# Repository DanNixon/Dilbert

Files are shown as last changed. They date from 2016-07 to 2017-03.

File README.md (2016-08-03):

# Dilbert



An interactive badge based on the ESP8266.

For getting started and general information see [GUIDE.md](GUIDE.md).

## Features

- ESP8266
- Colour LCD
- D-pad + A/B buttons
- 8 NeoPixels
- UART, i2c, digital IO and NeoPixel expansion headers

## Links

- Repository: https://github.com/DanNixon/Dilbert
- Travis CI: https://travis-ci.org/DanNixon/Dilbert
- Documentation: http://dannixon.github.io/Dilbert

## Contributing code

Cool stuff to run on the badge is very welcome.

See [CONTRIBUTING.md](CONTRIBUTING.md).

## Requirements

Uses the following Arduino libraries:

- [Adafruit ILI9341](https://github.com/Links2004/Adafruit_ILI9341) (the
  Links2004 fork can provide much faster display updates than the [Adafruit
  library](https://github.com/adafruit/Adafruit_ILI9341))
- [Adafruit GFX](https://github.com/adafruit/Adafruit-GFX-Library)
- [Adafruit NeoPixel](https://github.com/adafruit/Adafruit_NeoPixel)
- [Adafruit MCP23017](https://github.com/adafruit/Adafruit-MCP23017-Arduino-Library)
  (modified version included in this repository)
- [Universal Inputs](https://github.com/DanNixon/ArduinoUniversalInput)

## Parts

- ESP-12
  ([buy](https://www.adafruit.com/product/2491))
- 2.2" TFT display with ILI9341 driver
  ([buy](http://www.ebay.co.uk/itm/262448340175))
- [MCP23017](http://ww1.microchip.com/downloads/en/DeviceDoc/21952b.pdf)
  ([buy](http://www.mouser.co.uk/search/ProductDetail.aspx?R=0virtualkey0virtualkeyMCP23017-E-SO))
- [AP2112](http://www.diodes.com/_files/datasheets/AP2112.pdf)
  ([buy](http://www.digikey.co.uk/product-detail/en/diodes-incorporated/AP2112K-3.3TRG1/AP2112K-3.3TRG1DICT-ND/4505257))
- 8x NeoPixels
  ([buy](https://www.adafruit.com/products/1655))
- 6x switches
  ([buy](http://www.digikey.co.uk/product-detail/en/panasonic-electronic-components/EVQ-PE504K/P13589S-ND/1245482))
- 1uF and 10uF 0805 capacitors
- 1K and 10K 0805 resistors

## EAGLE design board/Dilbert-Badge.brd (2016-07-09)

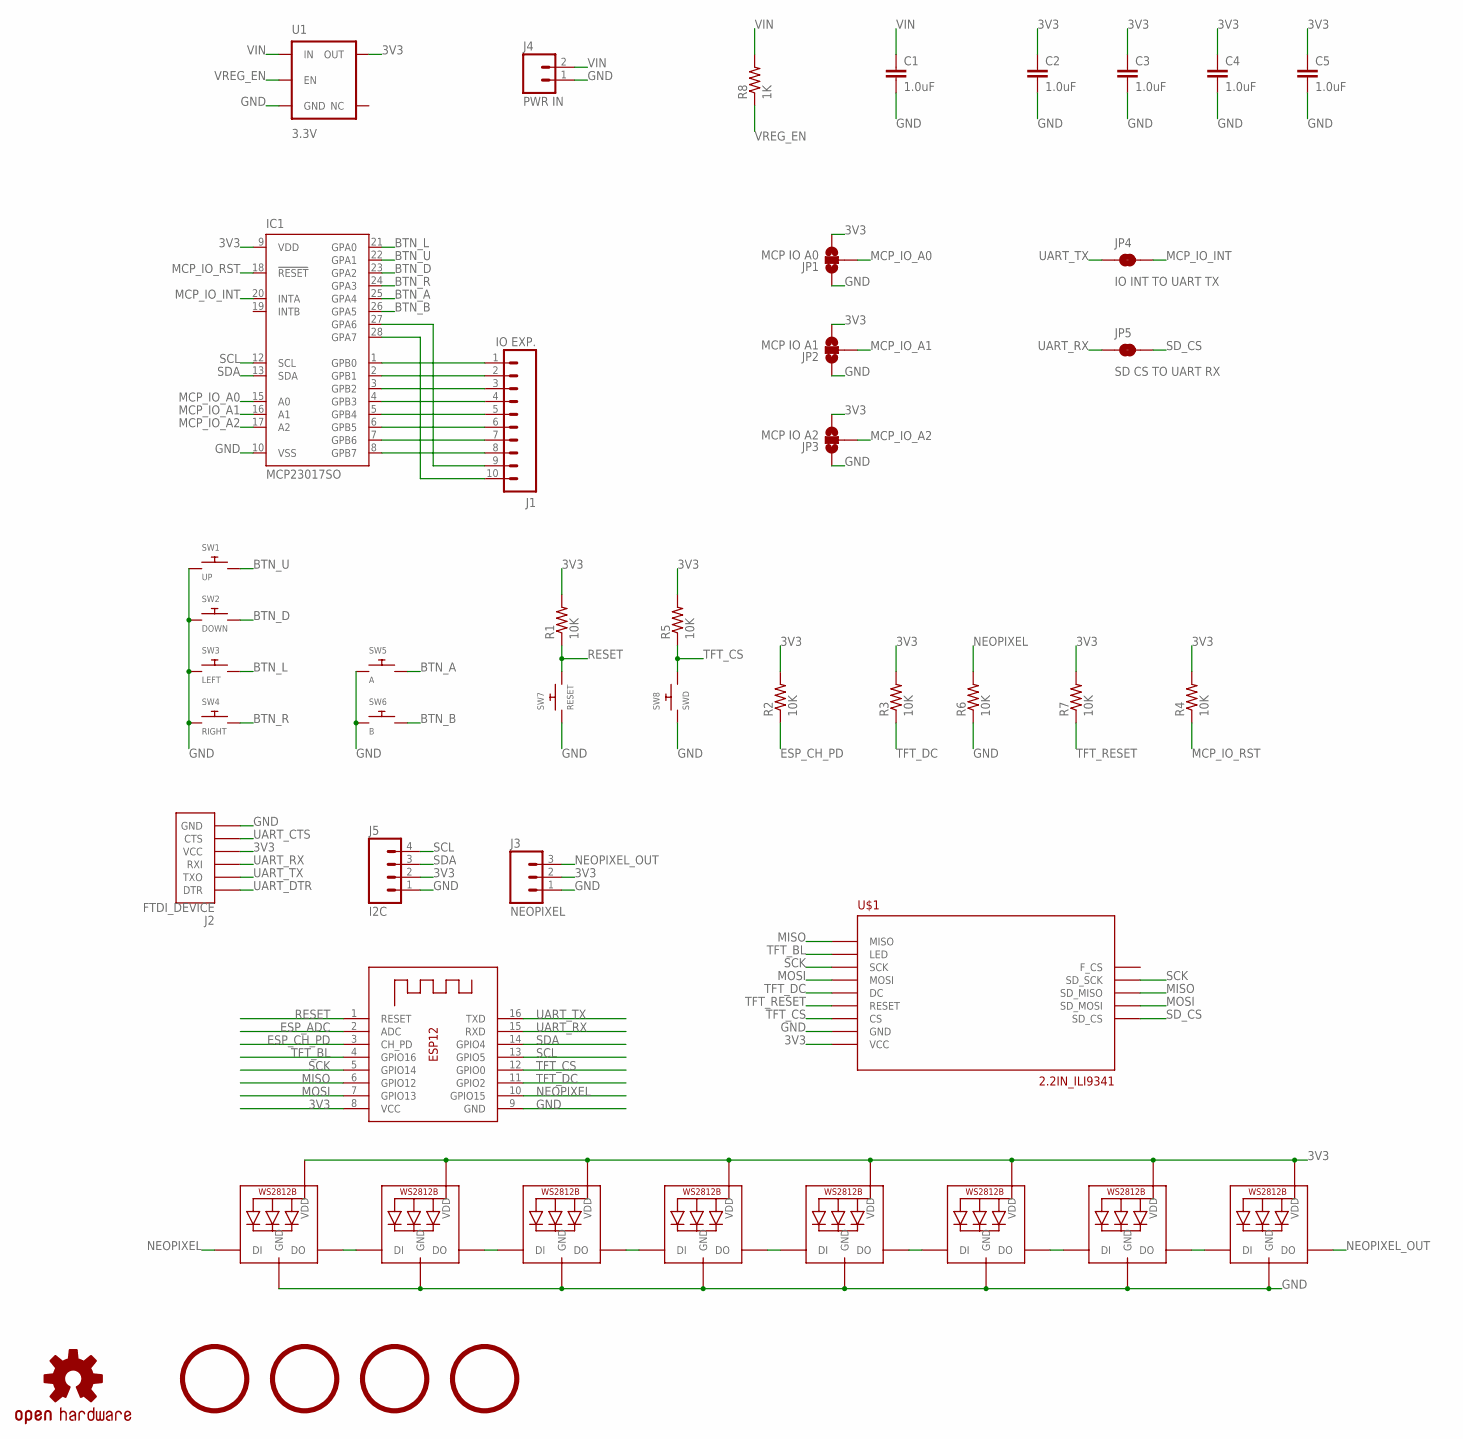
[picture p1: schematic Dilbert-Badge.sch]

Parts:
C1, C2, C3, C4, C5: 1.0uF; 0805-CAP
IC1: MCP23017SO; SO28W
J1: IO EXP.; 1X10
J2: FTDI_DEVICE; FTDI_DEVICE_SIDE
J3: NEOPIXEL; 1X03
J4: PWR IN; 1X02
J5: I2C; 1X04
JP1: MCP IO A0; PAD-JUMPER-3-NO_YES_SILK
JP2: MCP IO A1; PAD-JUMPER-3-NO_YES_SILK
JP3: MCP IO A2; PAD-JUMPER-3-NO_YES_SILK
JP4: IO INT TO UART TX; PAD-JUMPER-2-NC_BY_TRACE_NO_SILK
JP5: SD CS TO UART RX; PAD-JUMPER-2-NC_BY_TRACE_NO_SILK
LED1, LED2, LED3, LED4, LED5, LED6, LED7, LED8: WS2812B5050; WS2812B
LOGO1: OSHW-LOGOL; OSHW-LOGO-L
R1, R2, R3, R4, R5, R6, R7: 10K; R0805
R8: 1K; R0805
SW1: UP; TACT_PANA-EVQ
SW2: DOWN; TACT_PANA-EVQ
SW3: LEFT; TACT_PANA-EVQ
SW4: RIGHT; TACT_PANA-EVQ
SW5: A; TACT_PANA-EVQ
SW6: B; TACT_PANA-EVQ
SW7: RESET; TACT_PANA-EVQ
SW8: SWD; TACT_PANA-EVQ
U1: 3.3V; SOT23-5
U$1: 2.2IN_ILI9341
U$2, U$3, U$4, U$5: 5MM_MOUNTING_HOLE; 5MM_HOLE
X1: ESP-12

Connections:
3V3: C2.1, C3.1, C4.1, C5.1, IC1.9 (VDD), J2.P$4 (VCC), J3.2, J5.2, JP1.3, JP2.3, JP3.3, LED1.1-VDD (VDD), LED2.1-VDD (VDD), LED3.1-VDD (VDD), LED4.1-VDD (VDD), LED5.1-VDD (VDD), LED6.1-VDD (VDD), LED7.1-VDD (VDD), LED8.1-VDD (VDD), R1.2, R2.2, R3.2, R4.2, R5.2, R7.2, U1.5 (OUT), U$1.VCC, X1.8 (VCC)
BTN_A: IC1.25 (GPA4), SW5.P$2
BTN_B: IC1.26 (GPA5), SW6.P$2
BTN_D: IC1.23 (GPA2), SW2.P$2
BTN_L: IC1.21 (GPA0), SW3.P$2
BTN_R: IC1.24 (GPA3), SW4.P$2
BTN_U: IC1.22 (GPA1), SW1.P$2
ESP_ADC: X1.2 (ADC)
ESP_CH_PD: R2.1, X1.3 (CH_PD)
GND: C1.2, C2.2, C3.2, C4.2, C5.2, IC1.10 (VSS), J2.P$6 (GND), J3.1, J4.1, J5.1, JP1.1, JP2.1, JP3.1, LED1.3-GND (GND), LED2.3-GND (GND), LED3.3-GND (GND), LED4.3-GND (GND), LED5.3-GND (GND), LED6.3-GND (GND), LED7.3-GND (GND), LED8.3-GND (GND), R6.1, SW1.P$1, SW2.P$1, SW3.P$1, SW4.P$1, SW5.P$1, SW6.P$1, SW7.P$1, SW8.P$1, U1.2 (GND), U$1.GND, X1.9 (GND)
MCP_IO_A0: IC1.15 (A0), JP1.2
MCP_IO_A1: IC1.16 (A1), JP2.2
MCP_IO_A2: IC1.17 (A2), JP3.2
MCP_IO_INT: IC1.20 (INTA), JP4.2
MCP_IO_RST: IC1.18 (!RESET), R4.1
MISO: U$1.MISO, U$1.SD_MISO, X1.6 (GPIO12)
MOSI: U$1.MOSI, U$1.SD_MOSI, X1.7 (GPIO13)
unnamed: LED1.2-DOUT (DO), LED2.4-DIN (DI)
unnamed: IC1.1 (GPB0), J1.1
unnamed: IC1.2 (GPB1), J1.2
unnamed: IC1.3 (GPB2), J1.3
unnamed: IC1.4 (GPB3), J1.4
unnamed: IC1.28 (GPA7), J1.10
unnamed: IC1.27 (GPA6), J1.9
unnamed: IC1.8 (GPB7), J1.8
unnamed: IC1.7 (GPB6), J1.7
unnamed: IC1.6 (GPB5), J1.6
unnamed: IC1.5 (GPB4), J1.5
unnamed: LED2.2-DOUT (DO), LED3.4-DIN (DI)
unnamed: LED3.2-DOUT (DO), LED4.4-DIN (DI)
unnamed: LED4.2-DOUT (DO), LED5.4-DIN (DI)
unnamed: LED5.2-DOUT (DO), LED6.4-DIN (DI)
unnamed: LED6.2-DOUT (DO), LED7.4-DIN (DI)
unnamed: LED7.2-DOUT (DO), LED8.4-DIN (DI)
NEOPIXEL: LED1.4-DIN (DI), R6.2, X1.10 (GPIO15)
NEOPIXEL_OUT: J3.3, LED8.2-DOUT (DO)
RESET: R1.1, SW7.P$2, X1.1 (RESET)
SCK: U$1.SCK, U$1.SD_SCK, X1.5 (GPIO14)
SCL: IC1.12 (SCL), J5.4, X1.13 (GPIO5)
SDA: IC1.13 (SDA), J5.3, X1.14 (GPIO4)
SD_CS: JP5.2, U$1.SD_CS
TFT_BL: U$1.LED, X1.4 (GPIO16)
TFT_CS: R5.1, SW8.P$2, U$1.CS, X1.12 (GPIO0)
TFT_DC: R3.1, U$1.DC, X1.11 (GPIO2)
TFT_RESET: R7.1, U$1.RESET
UART_CTS: J2.P$5 (CTS)
UART_DTR: J2.P$1 (DTR)
UART_RX: J2.P$3 (RXI), JP5.1, X1.15 (RXD)
UART_TX: J2.P$2 (TXO), JP4.1, X1.16 (TXD)
VIN: C1.1, J4.2, R8.2, U1.1 (IN)
VREG_EN: R8.1, U1.3 (EN)

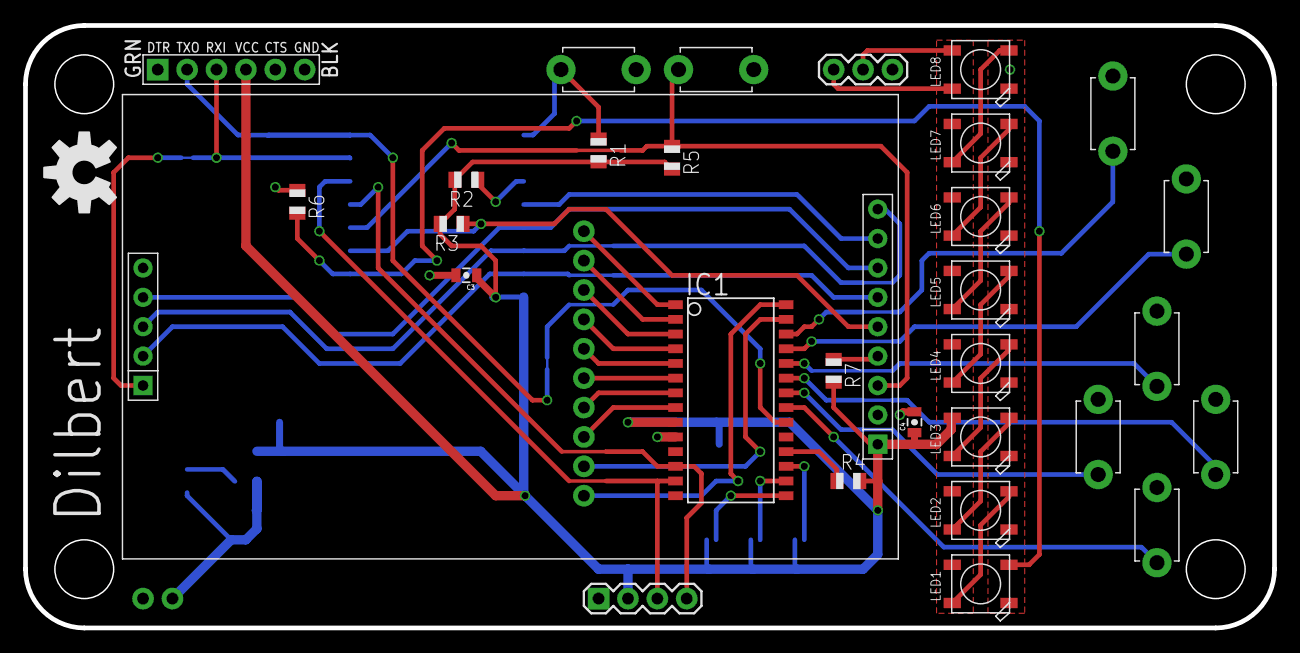
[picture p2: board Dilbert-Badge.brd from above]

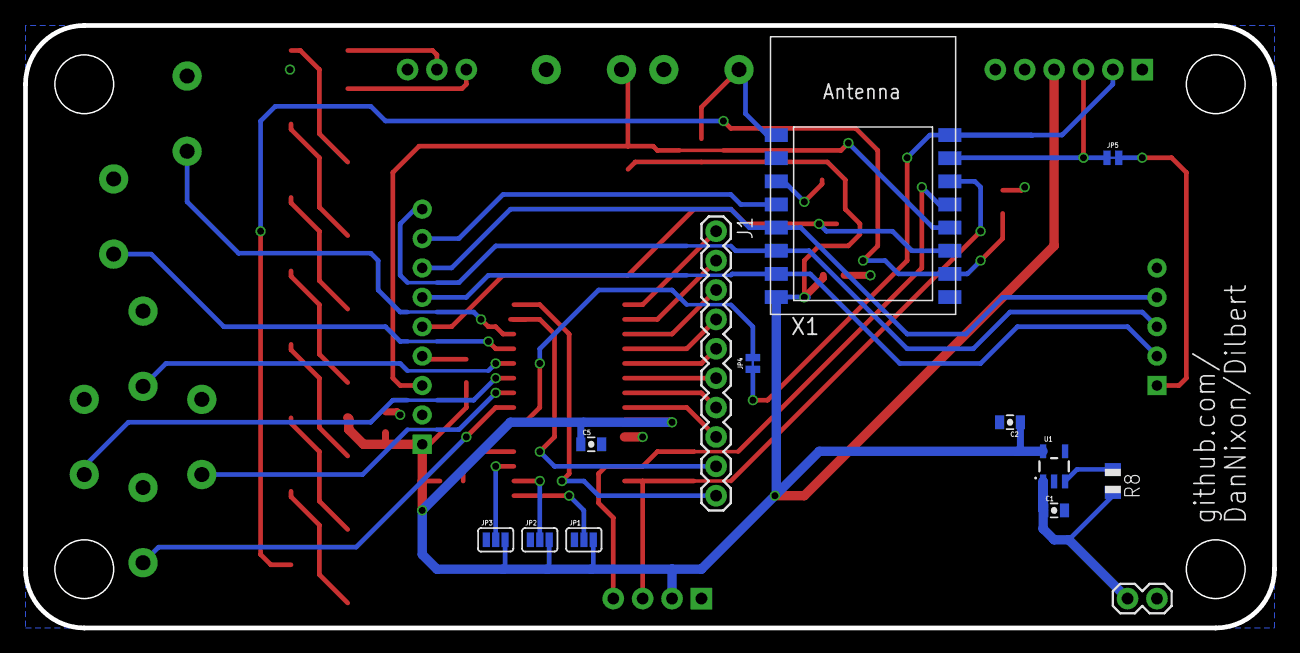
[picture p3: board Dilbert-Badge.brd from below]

Board: 2 copper layers, 108.0 x 52.1 mm, 48 parts (13 on the bottom side), 48 nets.

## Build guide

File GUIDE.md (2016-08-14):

# Guide

This aims to provide a general overview of the badge, important stuff,
troubleshooting and building/flashing.

## Power

**The *PWR IN* header accepts up to 6v only**, this is good for either a USB
power bank or a single cell lithium battery.

**There is no reverse polarity protection!** I don't know exactly what would
happen if you connected the supply in reverse polarity, I haven't tried.

If using a bare battery keep in mind that **there is no voltage detection or
protection on the board** (other than the internal supply voltage measurement on
the ESPs ADC) and that the regulator will operate as far down as 3.3V.

Therefore it is your responsibility to make sure the cell voltage of a battery
used to power the board does not fall too low.

An ideal battery to power the board if only used for low power applications
(i.e. no WiFi, no NeoPixels and no external modules) is a 240mAh or 380mAh
micro quad (e.g. Hubsan) battery.

I find that when the battery voltage does start to fall the MCP23017 is the
first device to fail, which is noticeable by the buttons becoming unresponsive.

## Assembly

Most of this is self explanatory, but just a few pointers:

- Do not reflow solder the ESP12 (reflowing my bridge vias on the ESP and the
  Dilbert board)
- Reflow solder the NeoPixels (it is much more difficult to make an arse of
  reflowing them)
- Mod wires must be added to connect the ground of the first NeoPixel and the
  VCC of the last NeoPixel
- Make sure everything works before soldering in the LCD, the holes are tight
  enough for a good connection to be made without soldering

## MCP23017

There are a pair of solder bridge pads near the *X1* designator (bottom left of
the ESP12) that connect the interrupt output of the MCP23017 to the TXd of the
ESP8266 UART.

This connection is made by default using a small trace between the pads. It can
be removed easily with a small screwdriver by scraping the trace between the
pads away and remade by flowing solder over the pads.

If you have issues flashing the board that are not due to lack of power then try
breaking this connection.

## Software

There are a few examples that show how to do most things you would want to do on
the board.

Graphics are handled by the [Adafruit GFX
library](https://github.com/adafruit/Adafruit-GFX-Library), NeoPixels are
handled by the [Adafruit NeoPixel
library](https://github.com/adafruit/Adafruit_NeoPixel), if you choose to use
the additional IO pins of the MCP23017 they are accessed using the [Adafruit
MCP23017
library](https://github.com/adafruit/Adafruit-MCP23017-Arduino-Library), buttons
are managed using [Universal
Inputs](https://github.com/DanNixon/ArduinoUniversalInput).

Instances to the drivers of each of these devices are provided by the `Dilbert`
object:

- Display: `Dilbert::display()`
- NeoPIxels: `Dilbert::neoPixels()`
- MCP23017: `Dilbert::io()`
- Buttons: `Dilbert::buttons()`

The backlight intensity can be set using either `Dilbert::setBacklight(uint16_t)`
where the parameter is a value between 0 and 1023 or
`Dilbert::setBacklightOn(bool)` where the parameter is a boolean denoting either
full brightness or off.

When handling buttons events from Universal Inputs the IDs are enumerated as:

- `Dilbert::BUTTON_UP`
- `Dilbert::BUTTON_DOWN`
- `Dilbert::BUTTON_LEFT`
- `Dilbert::BUTTON_RIGHT`
- `Dilbert::BUTTON_A`
- `Dilbert::BUTTON_B`

The values of the IDs correspond to the IO on the MCP23017 the button is
connected to.

If using the spare IO pins of the MCP23017 be sure not to change the global
interrupt configuration or the individual pin configurations of any pin
connected to a button.

## Flashing

- Clone this repository
- Run `./init_submodules.sh` (this downloads git submodules containing
  libraries)
- Install [PlatfromIO](http://platformio.org)
- Connect the badge via an FTDI adapter
- Hold the *SWD* switch and press the *RESET* switch, keeping *SWD* pressed
  while the ESP8266 resets (the LED on the ESP12 should blink once)
- `cd firmware`
- `pio run -t upload`
- ???
- Profit

## SD card slot

There is an SD card slot, it shares the SPI bus with the display.

It's chip select pin is connected to the RXd pin of the ESP8266 UART.

I have not tested it but it should probably work OK with the
[SdFat](https://github.com/greiman/SdFat) library.

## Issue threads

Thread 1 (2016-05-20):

Board design

DanNixon, 2016-05-20:
- [x] Lanyard holes
- [x] ESP8266
- [x] Display (LCD)
- [x] IO expansion (MCP23017)
- [x] Buttons (D-pad + A/B)
- [x] NeoPixels
- [x] Buck converter

Closed 2016-06-11.

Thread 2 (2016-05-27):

Hardware abstraction library

DanNixon, 2016-05-27:
- [x] Display
- [x] Display backlight
- [x] Buttons
- [x] Lights
- [x] IO

DanNixon, 2016-05-27:
Probably need to use the port expander for chip select, data select and reset pins of SPI devices.

Closed 2016-06-12.

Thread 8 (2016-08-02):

Officially switch to the faster fork of the display driver

DanNixon, 2016-08-02:
Test it and fix any issues.

All being well update the docs to point to this fork.

Closed 2016-08-03.

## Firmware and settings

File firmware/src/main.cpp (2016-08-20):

/*!
 * @file
 * @author Dan Nixon
 * @brief Example with application manager. Intended to be used as the badge
 *        firmware.
 */

/* #include <GDBStub.h> */

#include <SPI.h>
#include <Wire.h>
#include <Adafruit_GFX.h>
#include <Adafruit_NeoPixel.h>
#include <Adafruit_ILI9341.h>
#include <UniversalInputManager.h>
#include <IButton.h>

#include <Adafruit_MCP23017.h>
#include <Dilbert.h>
#include <AppManager.h>
#include <MenuApp.h>
#include <SystemSettingsApp.h>
#include <SPIFFSConfigService.h>
#include <ConfigService.h>

#include "DebugApp.h"
#include "ProfileApp.h"
#include "StarsApp.h"
#include "DilbertApp.h"
#include "Conways.h"
#include "NeoTestApp.h"

/* #define USE_BUTTON_INTERRUPTS */

Dilbert badge;                 //!< Badge driver
AppManager appManager(&badge); //!< Badge application manager

#ifdef USE_BUTTON_INTERRUPTS
volatile bool gpio_interrupt;
#endif

void setup()
{
  badge.begin();

  /* Set storage */
  ConfigService::Instance().setStorage(new SPIFFSConfigService());

  badge.buttons().poll();
  IButton * bButton = (IButton *)badge.buttons().getDevice(Dilbert::BUTTON_B);

  /* Reset settings if B is held on startup */
  if (bButton->isActive())
  {
    ConfigService::Instance().save();
  }
  else
  {
    /* Load config or save the default values if it is not set */
    if(!ConfigService::Instance().load())
      ConfigService::Instance().save();
  }

  /* Add the app menu application
   * Typically this shoud always be the first added */
  appManager.addApp(new MenuApp(2));

  /* Add other applications */
  appManager.addApp(new SystemSettingsApp());
  appManager.addApp(new ProfileApp());
  appManager.addApp(new DebugApp());
  appManager.addApp(new StarsApp());
  appManager.addApp(new DilbertApp());
  appManager.addApp(new Conways());
  appManager.addApp(new NeoTestApp());

  /* Small delay before app manager start (which turns on backlight) */
  delay(100);

  /* Must call this after adding all apps */
  appManager.begin();

#ifdef USE_BUTTON_INTERRUPTS
  /* Button interrupt setup */
  gpio_interrupt = false;
  attachInterrupt(Dilbert::MCP23017_INT_GPIO, handle_int, FALLING);
#endif
}

void loop()
{
  appManager.run();

#ifdef USE_BUTTON_INTERRUPTS
  if (gpio_interrupt)
  {
    badge.buttons().poll();
    gpio_interrupt = false;
  }
#else
  badge.buttons().poll();
#endif
}

#ifdef USE_BUTTON_INTERRUPTS
/**
 * @brief Handle MCP23017 interrupt.
 */
void handle_int()
{
  gpio_interrupt = true;
}
#endif

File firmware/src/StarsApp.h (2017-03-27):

/*! @file */

#pragma once

#include <App.h>

struct Star
{
  long col;
  float x;
  float y;
  int size;
};

/**
 * @class StarsApp
 * @author Iain Yarnall
 * @brief Displays Starfield
 */
class StarsApp : public App
{
public:
  static const int STAR_COUNT = 100; /* Number of Stars */

public:
  StarsApp()
      : App("Stars")
  {
  }

  virtual ~StarsApp()
  {
  }

  /**
   * @copydoc App::onEntry
   */
  virtual void onEntry()
  {
    App::onEntry();
    /* Clear the screen */
    m_badge->display().fillScreen(ILI9341_BLACK);

    for (int a = 0; a < STAR_COUNT; a++)
    {
      newRandomStar(a);
      drawStar(a);
    }
  }

  /**
   * @copydoc App:run
   */
  virtual void run()
  {
    App::run();

    /* Keep backlight on */
    m_manager->feedBacklight(BACKLIGHT_STATE_DIM);

    if (millis() >= m_lastRan + m_frameDelay and m_mode != 5)
    {
      m_lastRan = millis();
      for (int a = 0; a < STAR_COUNT; a++)
      {
        hideStar(a);
        if (m_mode == 0) /* LEFT */
        {
          m_stars[a].x += m_speed;
          if (m_stars[a].x >= 240)
          {
            newRandomStar(a);
            m_stars[a].x = random(m_speed);
          }
        }
        else if (m_mode == 1) /* UP */
        {
          m_stars[a].y -= m_speed;
          if (m_stars[a].y < 0)
          {
            newRandomStar(a);
            m_stars[a].y = 319 - random(m_speed);
          }
        }
        else if (m_mode == 2) /* DOWN */
        {
          m_stars[a].y += m_speed;
          if (m_stars[a].y >= 320)
          {
            newRandomStar(a);
            m_stars[a].y = random(m_speed);
          }
        }
        else if (m_mode == 3) /* RIGHT */
        {
          m_stars[a].x -= m_speed;
          if (m_stars[a].x < 0)
          {
            newRandomStar(a);
            m_stars[a].x = 239 - random(m_speed);
          }
        }
        else if (m_mode == 4) /* FORWARDS */
        {
          m_stars[a].x += (m_stars[a].x - 120) * m_zoom;
          m_stars[a].y += (m_stars[a].y - 160) * m_zoom;
          if (m_stars[a].x < 0 or m_stars[a].x >= 240 or m_stars[a].y < 0 or m_stars[a].y >= 320)
          {
            newRandomStar(a);
          }
        }
        drawStar(a);
      }
    }
  }

  /**
  * @copydoc App::handleButton
  */
  virtual bool handleButton(IButton *button)
  {
    if (App::handleButton(button))
      return true;

    if (button->isActive())
    {
      m_mode = button->getID();
      return true;
    }

    return false;
  }

private:
  struct Star m_stars[STAR_COUNT];
  long m_lastRan = millis();
  int m_frameDelay = 150;
  float m_zoom =
      .1; /* Speed of forward motion (% of distance from centre point to add each frame) */
  int m_speed = 10; /* No of pixels to travel for each frame in L/R/U/D modes */
  int m_mode = 5;   /* Direction of travel (relates to button IDs) */

  void newRandomStar(int a)
  {
    m_stars[a].col = random(16777215);
    m_stars[a].size = random(3);
    m_stars[a].size = random(m_stars[a].size);
    do
    {
      m_stars[a].x = random(240);
      m_stars[a].y = random(320);
    } while (m_stars[a].x == 120 and m_stars[a].y == 160);
  }

  void hideStar(int a)
  {
    if (m_stars[a].size == 0)
    {
      m_badge->display().drawPixel(int(m_stars[a].x), int(m_stars[a].y), 0);
    }
    else
    {
      m_badge->display().fillCircle(int(m_stars[a].x), int(m_stars[a].y), m_stars[a].size, 0);
    }
  }

  void drawStar(int a)
  {
    if (m_stars[a].size == 0)
    {
      m_badge->display().drawPixel(int(m_stars[a].x), int(m_stars[a].y), m_stars[a].col);
    }
    else
    {
      m_badge->display().fillCircle(int(m_stars[a].x), int(m_stars[a].y), m_stars[a].size,
                                    m_stars[a].col);
    }
  }
};

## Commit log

2016-05-20 start board
    [Dilbert-Badge.brd, Dilbert-Badge.sch]
2016-05-20 add switches, initial layout
    [Dilbert-Badge.brd, Dilbert-Badge.sch]
2016-05-20 a little more work
    [Dilbert-Badge.brd, Dilbert-Badge.sch]
2016-05-20 add IO expander, more general layout
    [Dilbert-Badge.brd, Dilbert-Badge.sch]
2016-05-22 add puller resistors and decouping
    [Dilbert-Badge.brd, Dilbert-Badge.sch]
2016-05-27 add initial library
    [Dilbert-Badge.brd, Dilbert-Badge.sch]
2016-05-27 Update board
    [ci skip]
    [Dilbert-Badge.brd, Dilbert-Badge.sch]
2016-05-27 More dev work
    [Dilbert-Badge.brd, Dilbert-Badge.sch]
2016-06-01 more work on board
    [Dilbert-Badge.brd, Dilbert-Badge.sch]
2016-06-04 more work
    [Dilbert-Badge.brd, Dilbert-Badge.sch]
2016-06-04 more neopixels are good
    [Dilbert-Badge.brd, Dilbert-Badge.sch]
2016-06-07 switch to hardware SPI with i2c port expander
    [Dilbert-Badge.brd, Dilbert-Badge.sch]
2016-06-08 get working again with interrups for port expander
    Curently HardwareDemo shows the port status of the MCP when the state of
    any pin changes, the backlight gets brighter to indicate the interrupt
    being fired.
2016-06-09 board updates
    [Dilbert-Badge.brd, Dilbert-Badge.sch]
2016-06-09 more board layout
    [Dilbert-Badge.brd, Dilbert-Badge.sch]
2016-06-09 more layout
    [Dilbert-Badge.brd, Dilbert-Badge.sch]
2016-06-09 correct switches, more layout
    [Dilbert-Badge.brd, Dilbert-Badge.sch]
2016-06-09 ERC/DRU checks
    [Dilbert-Badge.brd, Dilbert-Badge.sch]
2016-06-09 add regulator, tidy layout
    [Dilbert-Badge.brd, Dilbert-Badge.sch]
2016-06-10 clean up text, maximise gropund plane width
    [Dilbert-Badge.brd]
2016-06-10 add hole for landscape lanyard
    [Dilbert-Badge.brd, Dilbert-Badge.sch]
2016-06-10 swap left/right buttons
    [Dilbert-Badge.brd, Dilbert-Badge.sch]
2016-06-10 Moved layout for better hold position.
    [Dilbert-Badge.brd]
2016-06-10 Revert "Moved layout for better hold position."
    This reverts commit 4734362e310bc9f544577fd27d433fa3af5f158a.
    [Dilbert-Badge.brd]
2016-06-10 Redo Alistair's new layout
    [Dilbert-Badge.brd, Dilbert-Badge.sch]
2016-06-10 update DRC
    [Dilbert-Badge.brd]
2016-06-11 update lcd pads and routing
    [Dilbert-Badge.brd, Dilbert-Badge.sch]
2016-06-11 add button manager
2016-06-12 add buttons
2016-06-24 WIder power planes on NeoPixels
    Fixes #4
    [Dilbert-Badge.brd]
2016-06-29 get buttons working
2016-06-29 option of interrupts in demo
2016-06-29 more power notes
2016-07-01 add app switching example
2016-07-09 small updates to board
    [Dilbert-Badge.brd]
2016-08-03 Officially recommend the Links2004 fork of TFT driver
    Closes #8
2016-08-05 Fix more includes, because Arduino
2016-08-09 Initial switch to platformio build
2016-08-14 small couple of fixes

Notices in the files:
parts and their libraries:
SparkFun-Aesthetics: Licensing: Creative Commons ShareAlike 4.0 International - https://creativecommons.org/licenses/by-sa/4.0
